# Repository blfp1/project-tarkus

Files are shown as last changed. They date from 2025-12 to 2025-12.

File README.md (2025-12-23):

# Project Tarkus 🚀

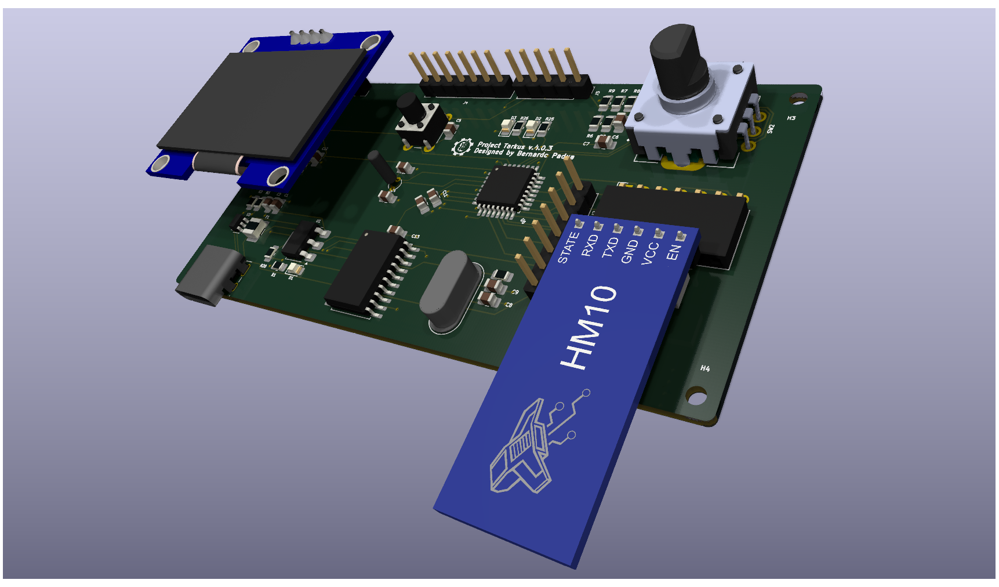
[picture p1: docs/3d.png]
Project Render


## Overview
**Project Tarkus** is a custom development board designed for embedded systems study and prototyping, built around the **STM32G030K6T6** microcontroller.

The project started as a requirement for the **PBLE01** course at **UNIFEI**. The original specification required a 16x2 LCD and a temperature sensor. I decided to modernize the scope by replacing these with a **1.3" OLED Display** and a **Bluetooth LE module**, creating a more versatile platform for IoT projects.

## Key Features
* **Microcontroller:** STM32G030K6T6 (ARM Cortex-M0+, 32KB Flash, 8KB RAM).
* **Connectivity:**
    * **USB-C** for power and data.
    * **MCP2200** USB-to-UART Bridge for easy serial debugging.
    * **Bluetooth LE (HM-10)** interface for wireless communication.
* **User Interface:**
    * I2C header for **OLED Display** (SSD1306/SH1106).
    * **Rotary Encoder** with push-button for menu navigation.
    * 2x User LEDs.
* **Storage & RTC:** External I2C EEPROM (24LC512) and 32.768kHz Crystal for precise RTC.

## Design Decisions
One of the main challenges was the need for **two independent UART buses**: one for the Bluetooth module and another for the USB-Serial bridge. This requirement led to the selection of the **STM32G030K6**, which offers sufficient hardware UART peripherals, replacing the originally planned MCU.

## Repository Structure
* `Hardware/`: KiCad project files (Schematics, PCB Layout, Libraries).
* `Docs/`: Project documentation, schematics in PDF, and 3D renders.
* `Datasheets/`: Main components' technical documentation.

## Author
Designed by **Bernardo Lamim Fogaça de Padua**
*Institute of Systems Engineering and Information Technology - UNIFEI*

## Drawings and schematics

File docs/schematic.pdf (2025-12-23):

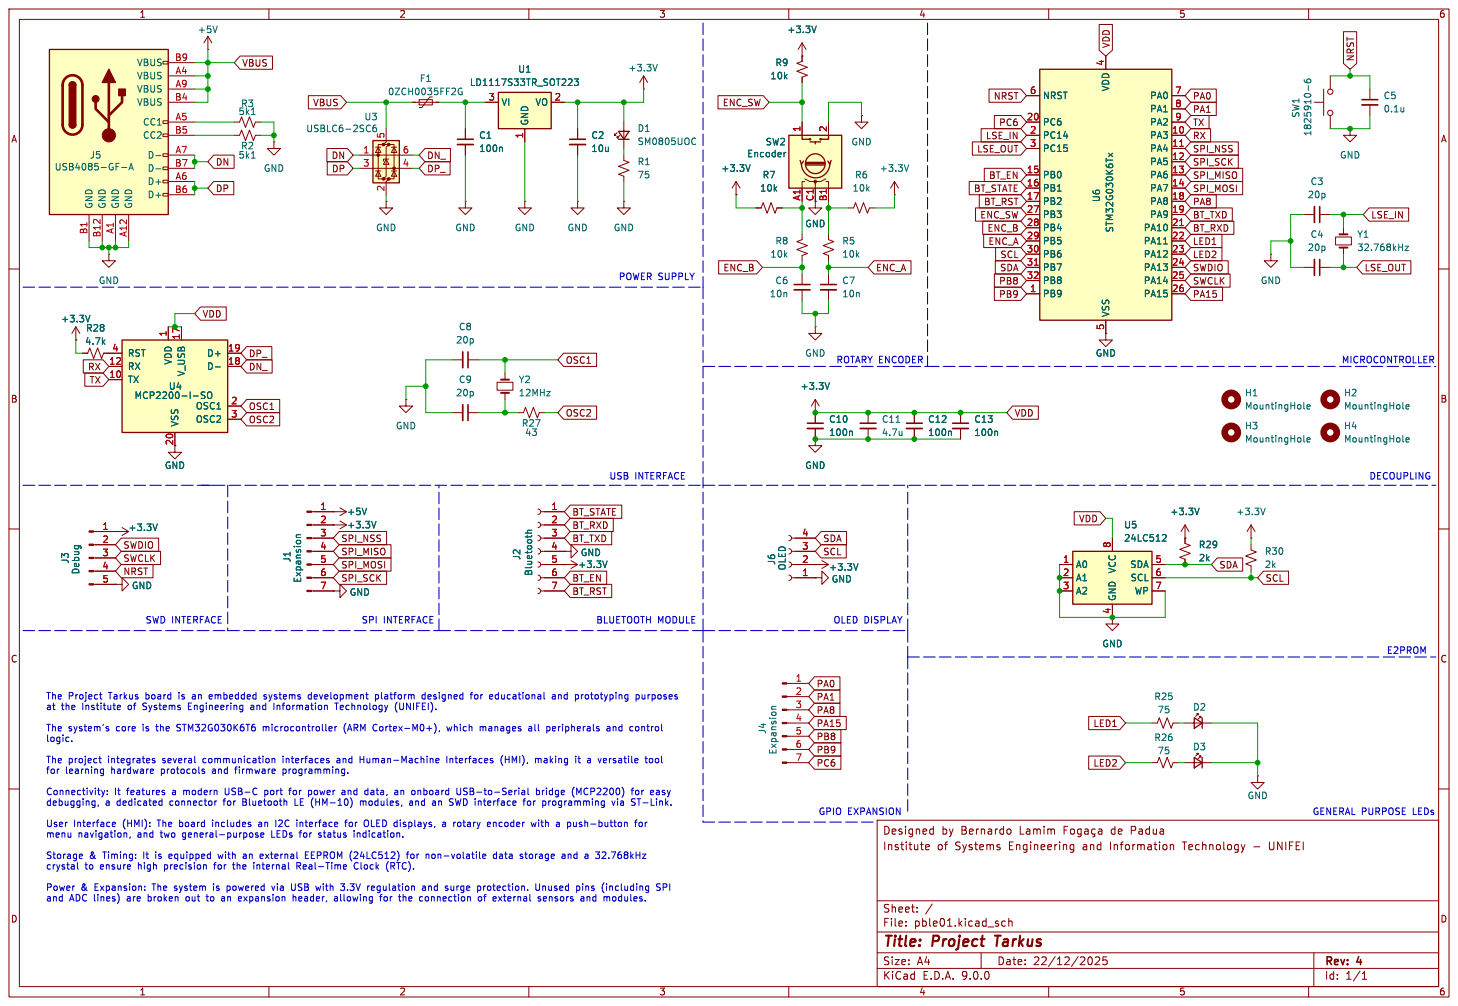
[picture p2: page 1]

4 SDA 5 SCL 6 WP 7 U6 STM32G030K6Tx NRST 6 PC6 20 PC14 2 PC15 3 PB0 15 PB1 16 PB2 17 PB3 27 PB4 28 PB5 29 PB6 30 PB7 31 PB8 32 PB9 1 VDD

File: pble01.kicad_sch Sheet: /
Id: 1/1 Title: Project Tarkus

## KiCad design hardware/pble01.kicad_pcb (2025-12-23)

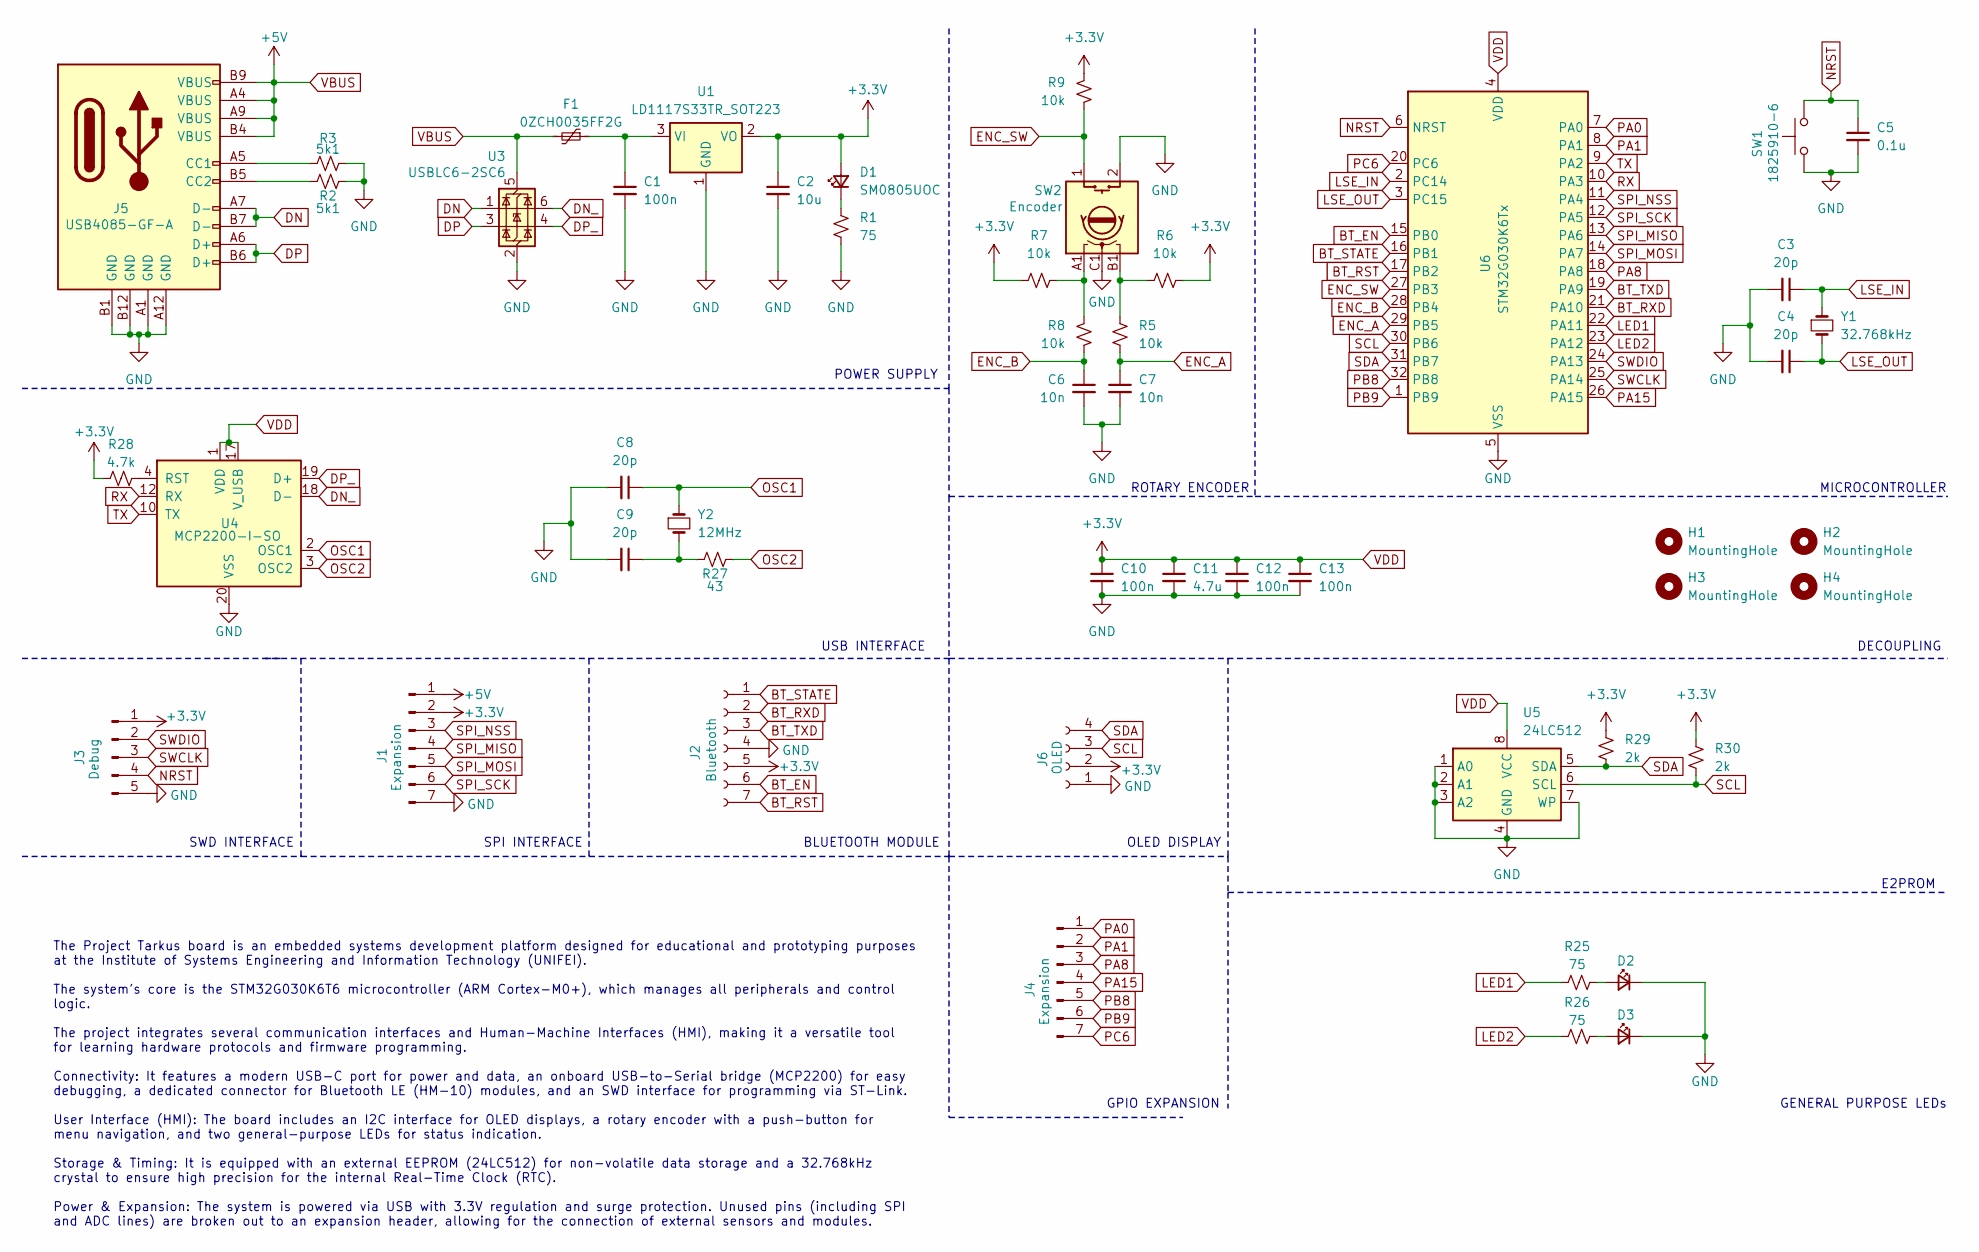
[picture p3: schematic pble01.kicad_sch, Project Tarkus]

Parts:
C1, C10, C12, C13: 100n; C_0805_2012Metric_Pad1.18x1.45mm_HandSolder
C2: 10u; C_0805_2012Metric_Pad1.18x1.45mm_HandSolder
C3, C4, C8, C9: 20p; C_0805_2012Metric_Pad1.18x1.45mm_HandSolder
C5: 0.1u; C_0805_2012Metric_Pad1.18x1.45mm_HandSolder
C6, C7: 10n; C_0805_2012Metric_Pad1.18x1.45mm_HandSolder
C11: 4.7u; C_0805_2012Metric_Pad1.18x1.45mm_HandSolder
D1, D2, D3: SM0805UOC; LED_0805_2012Metric_Pad1.15x1.40mm_HandSolder
F1: 0ZCH0035FF2G; Fuse_1210_3225Metric_Pad1.42x2.65mm_HandSolder
H1, H2, H3, H4: MountingHole; MountingHole_2.2mm_M2
J1, J4: Expansion; PinHeader_1x07_P2.54mm_Vertical
J2: Bluetooth; PinSocket_1x07_P2.54mm_Horizontal
J3: Debug; PinHeader_1x05_P2.54mm_Vertical
J5: USB4085-GF-A; USB_C_Receptacle_GCT_USB4085
J6: OLED; PinSocket_1x04_P2.54mm_Vertical
R1, R25, R26: 75; R_0805_2012Metric_Pad1.20x1.40mm_HandSolder
R2, R3: 5k1; R_0805_2012Metric_Pad1.20x1.40mm_HandSolder
R5, R6, R7, R8, R9: 10k; R_0805_2012Metric_Pad1.20x1.40mm_HandSolder
R27: 43; R_0805_2012Metric_Pad1.20x1.40mm_HandSolder
R28: 4.7k; R_0805_2012Metric_Pad1.20x1.40mm_HandSolder
R29, R30: 2k; R_0805_2012Metric_Pad1.20x1.40mm_HandSolder
SW1: 1825910-6; SW_PUSH_6mm_H7.3mm
SW2: Encoder; XDCR_PEC12R-4215F-S0024
U1: LD1117S33TR_SOT223; SOT-223-3_TabPin2
U3: USBLC6-2SC6; SOT-23-6
U4: MCP2200-I-SO; SOIC-20W_7.5x12.8mm_P1.27mm
U5: 24LC512; SOIC-8_3.9x4.9mm_P1.27mm
U6: STM32G030K6Tx; LQFP-32_7x7mm_P0.8mm
Y1: 32.768kHz; Crystal_DS26_D2.0mm_L6.0mm_Vertical
Y2: 12MHz; Crystal_HC49-4H_Vertical

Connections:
BT_EN: J2.6, U6.15 (PB0)
BT_RST: J2.7, U6.17 (PB2)
BT_RXD: J2.2, U6.21 (PA10)
BT_STATE: J2.1, U6.16 (PB1)
BT_TXD: J2.3, U6.19 (PA9)
DN: J5.A7 (D-), J5.B7 (D-), U3.1 (I/O1)
DN_: U3.6 (I/O1), U4.18 (D-)
DP: J5.A6 (D+), J5.B6 (D+), U3.3 (I/O2)
DP_: U3.4 (I/O2), U4.19 (D+)
ENC_A: C7.1, R5.1, U6.29 (PB5)
ENC_B: C6.1, R8.1, U6.28 (PB4)
ENC_SW: R9.1, SW2.1, U6.27 (PB3)
GND: C1.2, C2.2, C3.2, C4.2, C5.2, C6.2, C7.2, C8.2, C9.2, C10.2, C11.2, C12.2, C13.2, D2.1 (K), D3.1 (K), J1.7, J2.4, J3.5, J5.A1 (GND), J5.A12 (GND), J5.B1 (GND), J5.B12 (GND), J6.1, R1.2, R2.2, R3.2, SW1.1, SW2.2, SW2.C1, U1.1 (GND), U3.2 (GND), U4.20 (VSS), U5.1 (A0), U5.2 (A1), U5.3 (A2), U5.4 (GND), U5.7 (WP), U6.5 (VSS)
LED1: R25.1, U6.22 (PA11)
LED2: R26.1, U6.23 (PA12)
LSE_IN: C3.1, U6.2 (PC14), Y1.1
LSE_OUT: C4.1, U6.3 (PC15), Y1.2
NRST: C5.1, J3.4, SW1.2, U6.6 (NRST)
unnamed: C9.1, R27.1, Y2.2
unnamed: D1.1 (K), R1.1
unnamed: D2.2 (A), R25.2
unnamed: D3.2 (A), R26.2
unnamed: J5.A5 (CC1), R3.1
unnamed: J5.B5 (CC2), R2.1
unnamed: R5.2, R6.2, SW2.B1
unnamed: R7.1, R8.2, SW2.A1
unnamed: C1.1, F1.1, U1.3 (VI)
unnamed: R28.1, U4.4 (RST)
OSC1: C8.1, U4.2 (OSC1), Y2.1
OSC2: R27.2, U4.3 (OSC2)
PA0: J4.1, U6.7 (PA0)
PA1: J4.2, U6.8 (PA1)
PA8: J4.3, U6.18 (PA8)
PA15: J4.4, U6.26 (PA15)
PB8: J4.5, U6.32 (PB8)
PB9: J4.6, U6.1 (PB9)
PC6: J4.7, U6.20 (PC6)
RX: U4.12 (RX), U6.10 (PA3)
SCL: J6.3, R30.2, U5.6 (SCL), U6.30 (PB6)
SDA: J6.4, R29.2, U5.5 (SDA), U6.31 (PB7)
SPI_MISO: J1.4, U6.13 (PA6)
SPI_MOSI: J1.5, U6.14 (PA7)
SPI_NSS: J1.3, U6.11 (PA4)
SPI_SCK: J1.6, U6.12 (PA5)
SWCLK: J3.3, U6.25 (PA14)
SWDIO: J3.2, U6.24 (PA13)
TX: U4.10 (TX), U6.9 (PA2)
VBUS: F1.2, J1.1, J5.A4 (VBUS), J5.A9 (VBUS), J5.B4 (VBUS), J5.B9 (VBUS), U3.5 (VBUS)
VDD: C2.1, C10.1, C11.1, C12.1, C13.1, D1.2 (A), J1.2, J2.5, J3.1, J6.2, R6.1, R7.2, R9.2, R28.2, R29.1, R30.1, U1.2 (VO), U4.1 (VDD), U4.17 (V_USB), U5.8 (VCC), U6.4 (VDD)

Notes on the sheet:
POWER SUPPLY
OLED DISPLAY
SWD INTERFACE
USB INTERFACE
GENERAL PURPOSE LEDs
E2PROM
ROTARY ENCODER
The Project Tarkus board is an embedded systems development platform designed for educational and prototyping purposes at the Institute of Systems Engineering and Information Technology (UNIFEI). The system's core is the STM32G030K6T6 microcontroller (ARM Cortex-M0+), which manages all peripherals 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
SPI INTERFACE
DECOUPLING
GPIO EXPANSION
BLUETOOTH MODULE
MICROCONTROLLER

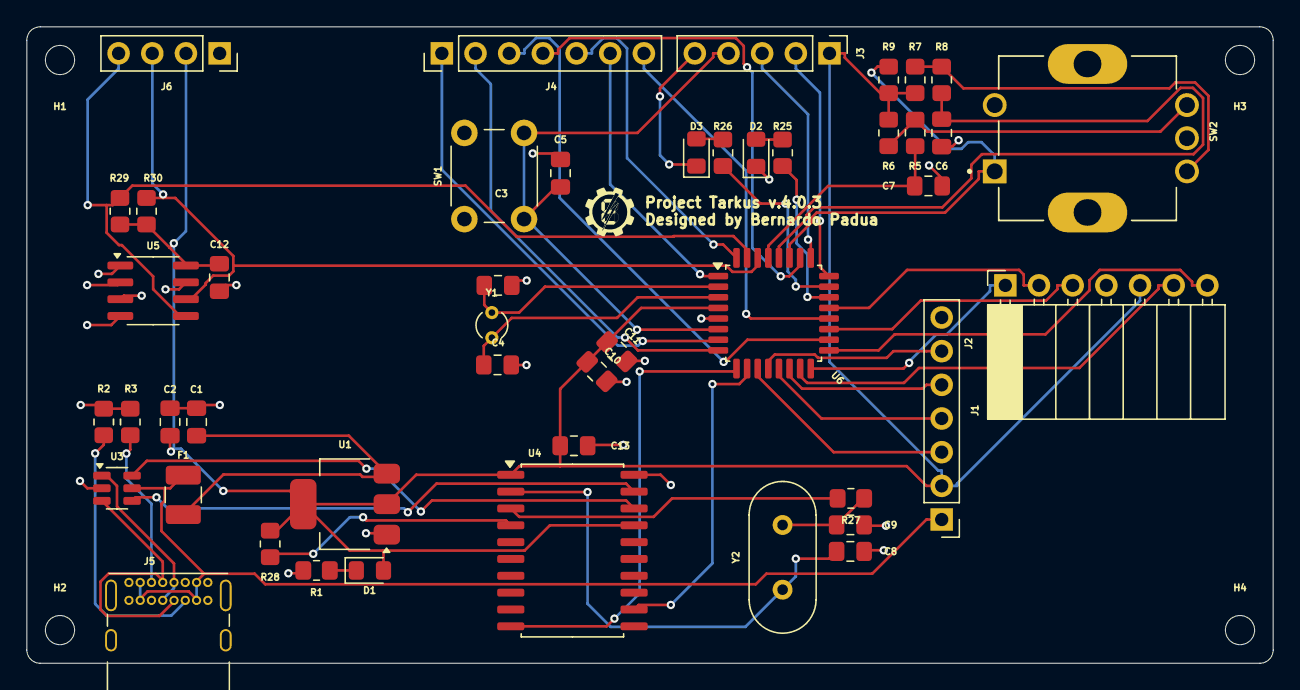
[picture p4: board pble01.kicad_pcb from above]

Board: 2 copper layers, 94.0 x 48.0 mm, 50 parts (0 on the bottom side), 49 nets.
